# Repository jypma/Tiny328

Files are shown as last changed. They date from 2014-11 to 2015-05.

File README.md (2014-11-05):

Tiny328
=======

This board is derived from the original Tiny328 project started by [Nathan Chantrell](http://nathan.chantrell.net/20130923/tiny328-mini-wireless-arduino-clone/). It has the following design goals:
- Software compatible with Arduino and JeeNode
- Includes an RFM12B radio module from HopeRF
- Easily mountable

Retaining the same form factor as the original Tiny328, I made the following changes:

- Redid the board in Kicad instead of Eagle
- Added two mounting holes
- Split up 3V3 and 5V power input headers
- Made the connection of RFM12B's DSSI pin to D4 optional by solder jumper
- Added footprints for an R1/R2 voltage divider from VCC into A0, so battery voltage
  can be reliably measured against a calibrated atmega 1.1V band gap reference.

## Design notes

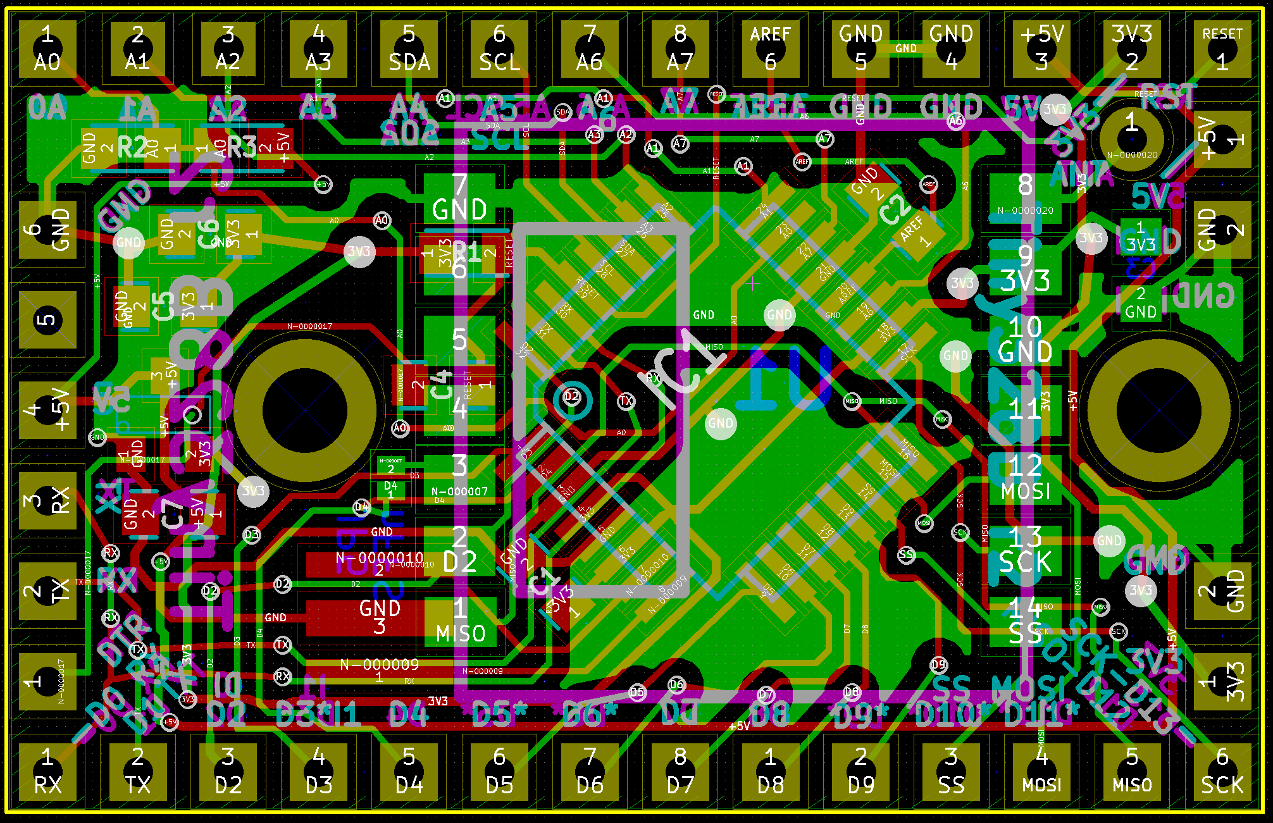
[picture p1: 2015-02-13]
tiny328.png

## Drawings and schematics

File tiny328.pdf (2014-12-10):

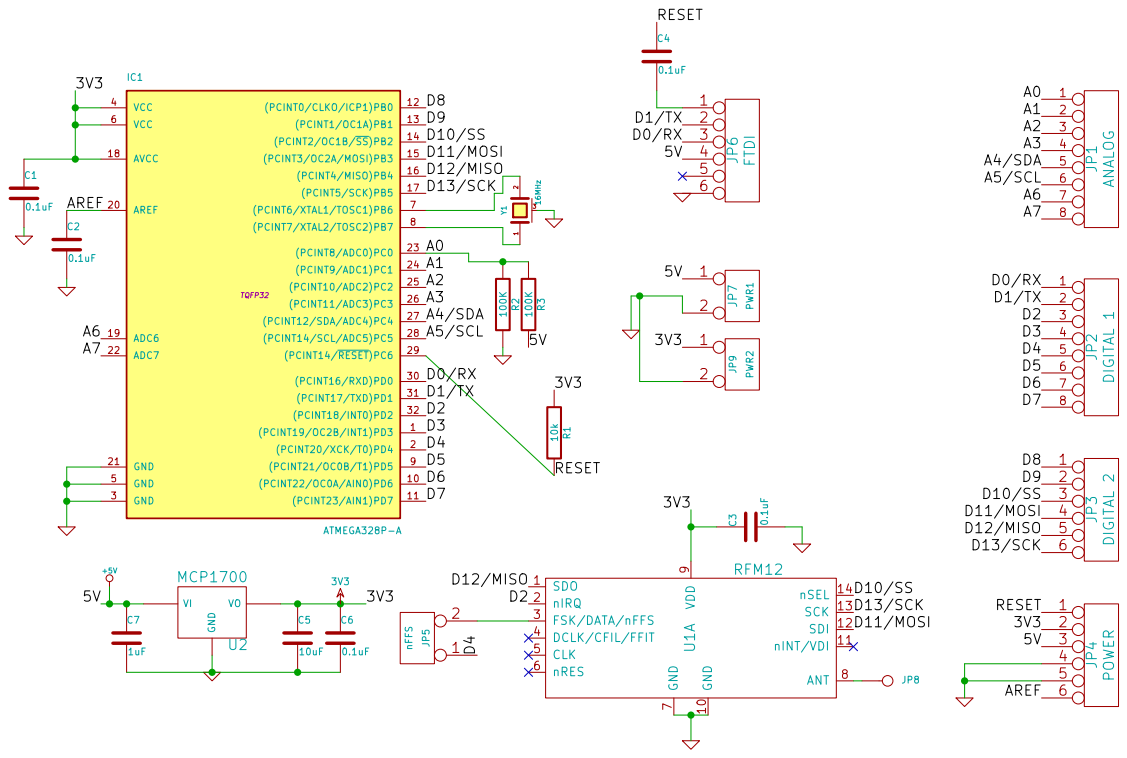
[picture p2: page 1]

Id: 1/1 Title: File: tiny328.sch
Sheet: /

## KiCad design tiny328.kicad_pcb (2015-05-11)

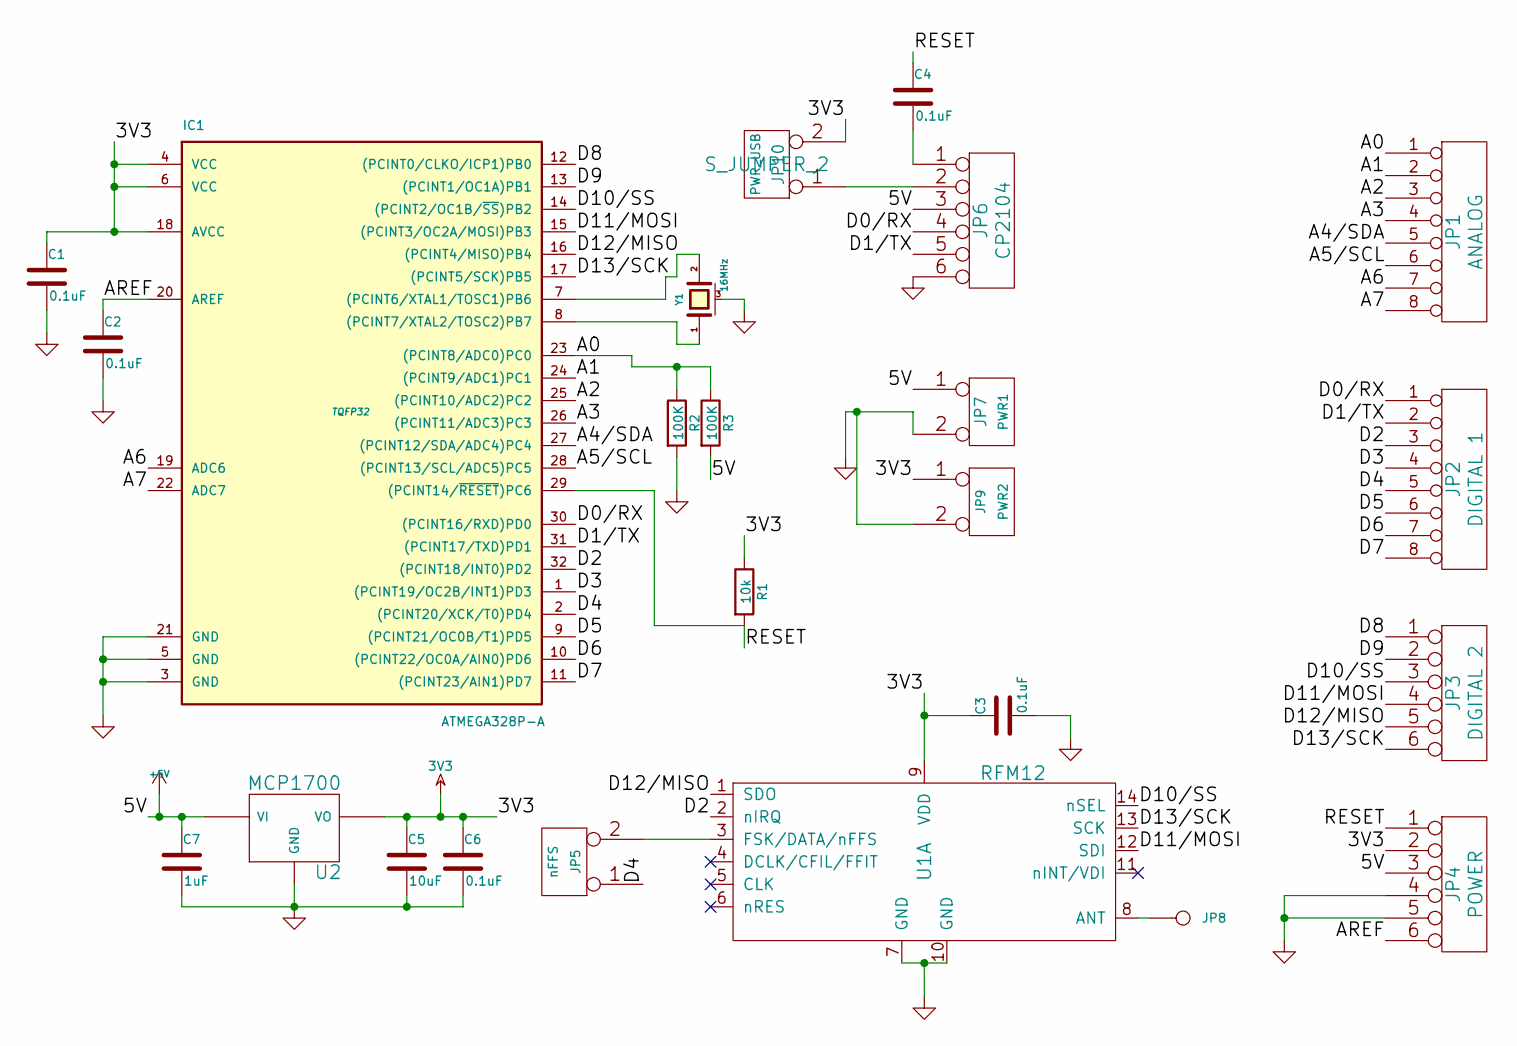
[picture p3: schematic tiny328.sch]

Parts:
C1, C2, C3, C4, C6: 0.1uF
C5: 10uF
C7: 1uF
IC1: ATMEGA328P-A; TQFP32
JP1: ANALOG
JP2: DIGITAL 1
JP3: DIGITAL 2
JP4: POWER
JP5: nFFS
JP6: CP2104
JP7: PWR1
JP8: ANT
JP9: PWR2
JP10: PWR_USB; S_JUMPER_2
R1: 10k
R2, R3: 100K
U1: RFM12
U2: MCP1700
Y1: 16MHz

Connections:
3V3: C1.1, C3.1, C5.1, C6.1, IC1.4 (VCC), IC1.6 (VCC), IC1.18 (AVCC), JP4.2, JP9.1, JP10.2 (PM), R1.1, U1.9 (VDD), U2.2 (VO)
+5V: C7.1, JP4.3, JP6.3, JP7.1, R3.2, U2.3 (VI)
/A0: IC1.23 ((PCINT8/ADC0)PC0), JP1.1, R2.1, R3.1
/A1: IC1.24 ((PCINT9/ADC1)PC1), JP1.2
/A2: IC1.25 ((PCINT10/ADC2)PC2), JP1.3
/A3: IC1.26 ((PCINT11/ADC3)PC3), JP1.4
/A4/SDA: IC1.27 ((PCINT12/SDA/ADC4)PC4), JP1.5
/A5/SCL: IC1.28 ((PCINT13/SCL/ADC5)PC5), JP1.6
/A6: IC1.19 (ADC6), JP1.7
/A7: IC1.22 (ADC7), JP1.8
/AREF: C2.1, IC1.20 (AREF), JP4.6
/D0/RX: IC1.30 ((PCINT16/RXD)PD0), JP2.1, JP6.4
/D1/TX: IC1.31 ((PCINT17/TXD)PD1), JP2.2, JP6.5
/D2: IC1.32 ((PCINT18/INT0)PD2), JP2.3, U1.2 (nIRQ)
/D3: IC1.1 ((PCINT19/OC2B/INT1)PD3), JP2.4
/D4: IC1.2 ((PCINT20/XCK/T0)PD4), JP2.5, JP5.1
/D5: IC1.9 ((PCINT21/OC0B/T1)PD5), JP2.6
/D6: IC1.10 ((PCINT22/OC0A/AIN0)PD6), JP2.7
/D7: IC1.11 ((PCINT23/AIN1)PD7), JP2.8
/D8: IC1.12 ((PCINT0/CLKO/ICP1)PB0), JP3.1
/D9: IC1.13 ((PCINT1/OC1A)PB1), JP3.2
/D10/SS: IC1.14 ((PCINT2/OC1B/~SS~)PB2), JP3.3, U1.14 (nSEL)
/D11/MOSI: IC1.15 ((PCINT3/OC2A/MOSI)PB3), JP3.4, U1.12 (SDI)
/D12/MISO: IC1.16 ((PCINT4/MISO)PB4), JP3.5, U1.1 (SDO)
/D13/SCK: IC1.17 ((PCINT5/SCK)PB5), JP3.6, U1.13 (SCK)
/RESET: C4.1, IC1.29 ((PCINT14/~RESET~)PC6), JP4.1, R1.2
GND: C1.2, C2.2, C3.2, C5.2, C6.2, C7.2, IC1.3 (GND), IC1.5 (GND), IC1.21 (GND), JP4.4, JP4.5, JP6.6, JP7.2 (PM), JP9.2 (PM), R2.2, U1.7 (GND), U1.10 (GND), U2.1 (GND), Y1.3 (case)
unnamed: C4.2, JP6.1
unnamed: IC1.7 ((PCINT6/XTAL1/TOSC1)PB6), Y1.2
unnamed: IC1.8 ((PCINT7/XTAL2/TOSC2)PB7), Y1.1
unnamed: JP5.2 (PM), U1.3 (FSK/DATA/nFFS)
unnamed: JP8.1, U1.8 (ANT)
unnamed: JP6.2, JP10.1

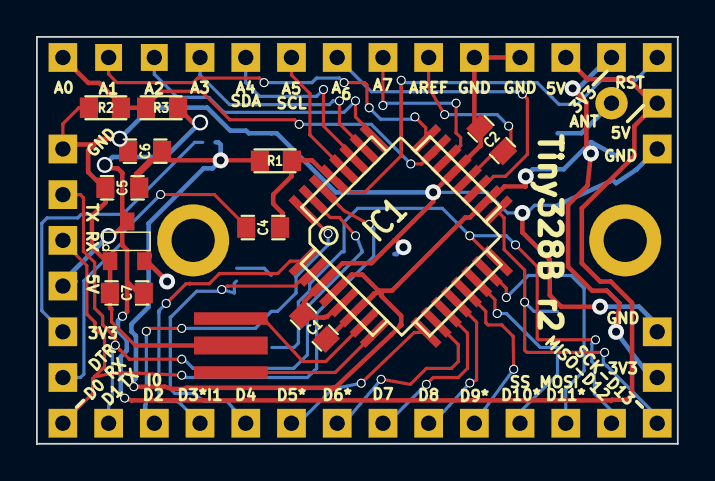
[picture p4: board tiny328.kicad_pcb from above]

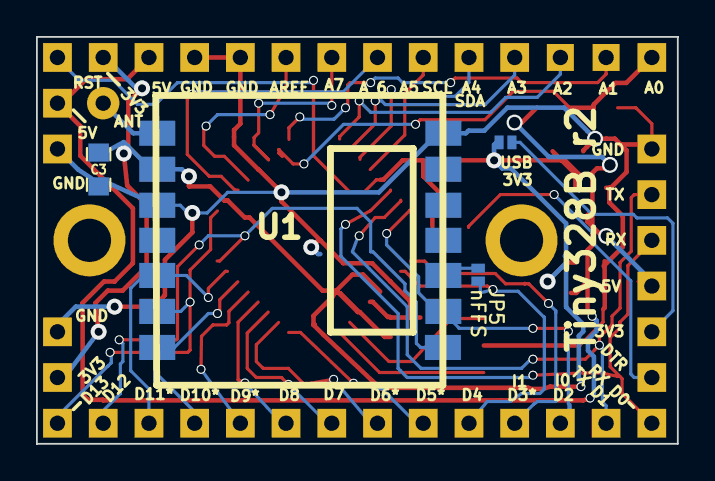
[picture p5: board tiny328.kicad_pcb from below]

Board: 2 copper layers, 35.6 x 22.6 mm, 26 parts (4 on the bottom side), 33 nets.

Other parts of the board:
1PIN, 1PIN#2: P***; 1pin_only

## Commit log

2014-10-02 initial version
    [tiny328.kicad_pcb, tiny328.sch]
2014-10-05 more routing, mounting holes
    [tiny328.kicad_pcb, tiny328.sch]
2014-10-06 increase power track widths
    [tiny328.kicad_pcb]
2014-10-12 widen vias
    [tiny328.kicad_pcb]
2014-10-27 all connected, flooded
    [tiny328.kicad_pcb]
2014-11-02 first version sent to osh park
    [tiny328.kicad_pcb]
2014-11-05 add board png
2014-12-10 Increase header hole & pad size Fix MCP1800 reversed pins 2 & 3 Fix FTDI reversed TX & RX Add MISO & SCK labels Remove silk screen around mounting holes Increase pad size for 0603's for hand soldering
    [tiny328.kicad_pcb, tiny328.sch]
2014-12-10 update layout pic and add schematic pdf
2014-12-12 adjust silk screen to be visible when headers are mounted
    [tiny328.kicad_pcb]
2015-02-13 increase antenna trace width
    [tiny328.kicad_pcb]
2015-04-23 small tweaks
    [tiny328.kicad_pcb]
2015-05-11 change to CP2104
    [tiny328.kicad_pcb, tiny328.sch]
